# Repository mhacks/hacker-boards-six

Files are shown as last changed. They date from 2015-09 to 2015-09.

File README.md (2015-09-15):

MHacks Six Hacker Boards
============
This repository contains the support files for the MHacks 6 Hacker Boards, presented at the Intro to Hardware Workshop ([presentation can be found here](https://docs.google.com/presentation/d/15O3TXqOf3Xi9S6ba83HRF5j0ccdkGcIPRQTYAptkbrs/edit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)). In the hardware folder is copies of the Eagle schematic and board layout for the board given to participants, and in the firmware folder is the library to simplify working with the board's LEDs, button, and potentiometer/knob - also called "peripherals".

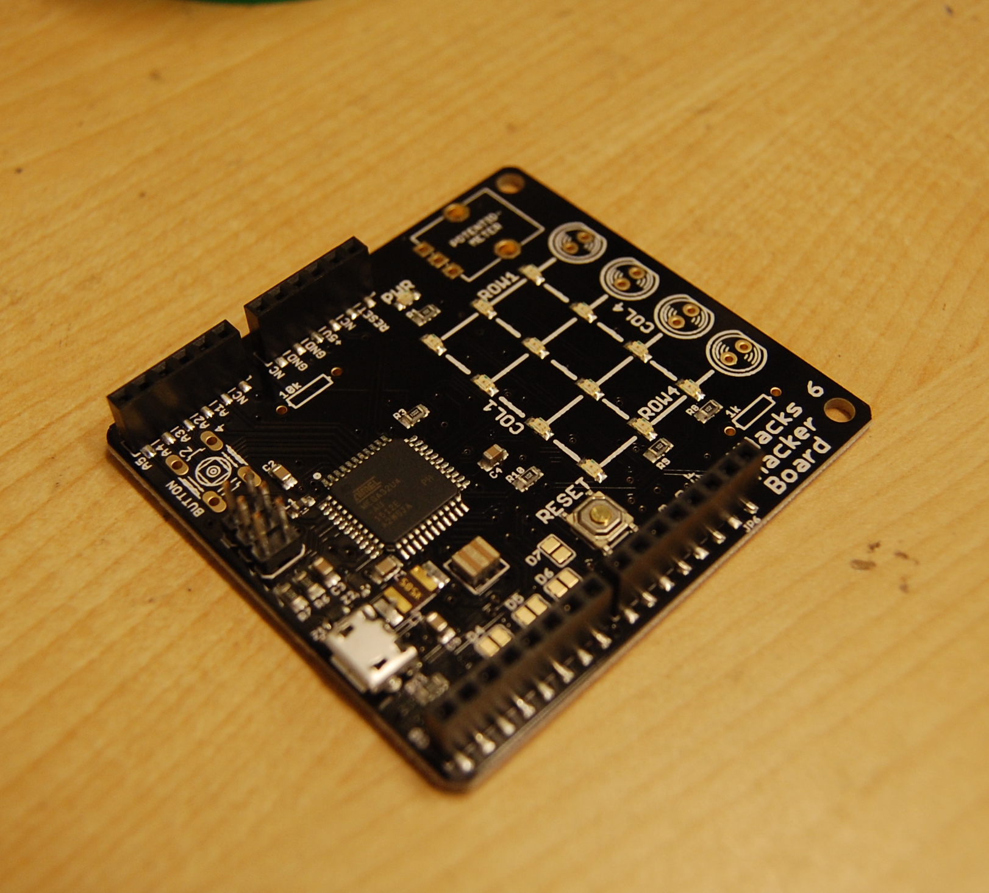
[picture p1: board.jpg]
A pretty Arduino LED shield

The MHacks Six Hacker Board. You like it? You should have come to the MHacks Six Intro to Hardware Workshop!

###How to Install the Library
* Inside of the Arduino IDE, go to Sketch->Import Library->Add Library.
* Choose the *HackerBoard* folder inside of the firmware folder.
* The Arduino IDE handles the rest!
* Be sure to check out the example animation (File->Examples->HackerBoard) if you're unsure how to work with the library, or what to do!

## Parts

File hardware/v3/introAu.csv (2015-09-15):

Part | Value | Device | Package | Description | Quantity |  | Digikey Part #
C1, C2 | 100nF | C-EUC0805 | C0805 | CAPACITOR, European symbol | 2 | 8 | 1276-1007-1-ND
JP1, JP2 |  | M06SMD-STRAIGHT-COMBO | 1X06_SMD_STRAIGHT_COMBO | Header 6 | 2 | 8 | S5598-ND
JP3, JP4 |  | M08SMD-COMBO | 1X08_SMD_COMBINED | Header 8 | 2 | 8 | S5600-ND
JP5 |  | M03X22X3_SILK_SM | 2X3 | 2x3 .1" header. | 1 | 4
L1 |  | WE-CBF_0805(WB/HS) | WE-CBF_0805(W=3.0) | WE-CBF SMD EMI Suppression Ferrite Bead | 1 | 4 | MH2029-300YCT-ND
LED1, LED17-28 |  | LEDCHIPLED_0805 | CHIPLED_0805 | LED | 13 | 52 | 160-1175-1-ND
LED4, LED9, LED10, LED14 |  | LED5MM | LED5MM | LEDs | 4 | 16 | 160-1952-ND
Q1 | CERAMIC_RESONATOR_SMD6M00G53Z | CERAMIC_RESONATOR_SMD6M00G53Z | CERAMIC_RESONATOR_SMD | Resonator | 1 | 4
R1, R2, R8, R9, R10 | 1k | R-US_R0805 | R0805 | RESISTOR, American symbol | 5 | 20 | RMCF0805JT1K00CT-ND
R5 | 10k | 1KOHM1/4W5%(PTH)HORIZ-KIT | AXIAL-0.3EZ | RES-08380 | 1 | 4 | CF14JT1K00CT-ND
R6, R7 | 22 | R-US_R0805 | R0805 | RESISTOR, American symbol | 2 | 8 | RMCF0805JT22R0CT-ND
S1 |  | TACT_BUTTON | B3F-10XX | OMRON SWITCH | 1 | 4 | SW400-ND
U$2 | ATMEGA32U4TQFP | ATMEGA32U4TQFP | SPARKFUN-DIGITALIC_TQFP44 |  | 1 | 4 | ATMEGA32U4-AU-ND
U$3 | USB_MICROB_0001LF | USB_MICROB_0001LF | USB_MICROB_CHEAPER |  | 1 | 4 | 609-4616-1-ND
U$5 |  | POT | ALPS_POT |  | 1 | 4 | P3C3103-ND
Z1, Z2 | zenor 3.6w | R-EU_R0603 | R0603 | RESISTOR, European symbol | 2 | 8 | MM3Z3V6T1GOSTR-ND | Change package to SOD-323

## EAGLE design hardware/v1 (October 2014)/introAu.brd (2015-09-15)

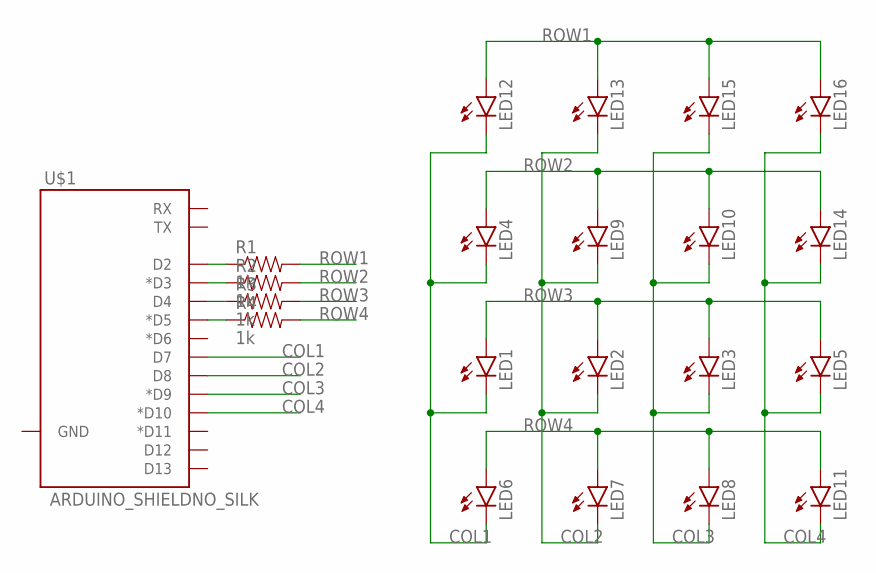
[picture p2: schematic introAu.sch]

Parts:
LED1, LED2, LED3, LED4, LED5, LED6, LED7, LED8, LED9, LED10, LED11, LED12, LED13, LED14, LED15, LED16: LED5MM
R1, R2, R3, R4: 1k; AXIAL-0.3EZ
U$1: ARDUINO_SHIELDNO_SILK; DUEMILANOVE_VIAS

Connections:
COL1: LED1.K (C), LED4.K (C), LED6.K (C), LED12.K (C), U$1.D7
COL2: LED2.K (C), LED7.K (C), LED9.K (C), LED13.K (C), U$1.D8
COL3: LED3.K (C), LED8.K (C), LED10.K (C), LED15.K (C), U$1.D9 (*D9)
COL4: LED5.K (C), LED11.K (C), LED14.K (C), LED16.K (C), U$1.D10 (*D10)
unnamed: R1.P$1 (1), U$1.D2
unnamed: R2.P$1 (1), U$1.D3 (*D3)
unnamed: R3.P$1 (1), U$1.D4
unnamed: R4.P$1 (1), U$1.D5 (*D5)
ROW1: LED12.A, LED13.A, LED15.A, LED16.A, R1.P$2 (2)
ROW2: LED4.A, LED9.A, LED10.A, LED14.A, R2.P$2 (2)
ROW3: LED1.A, LED2.A, LED3.A, LED5.A, R3.P$2 (2)
ROW4: LED6.A, LED7.A, LED8.A, LED11.A, R4.P$2 (2)

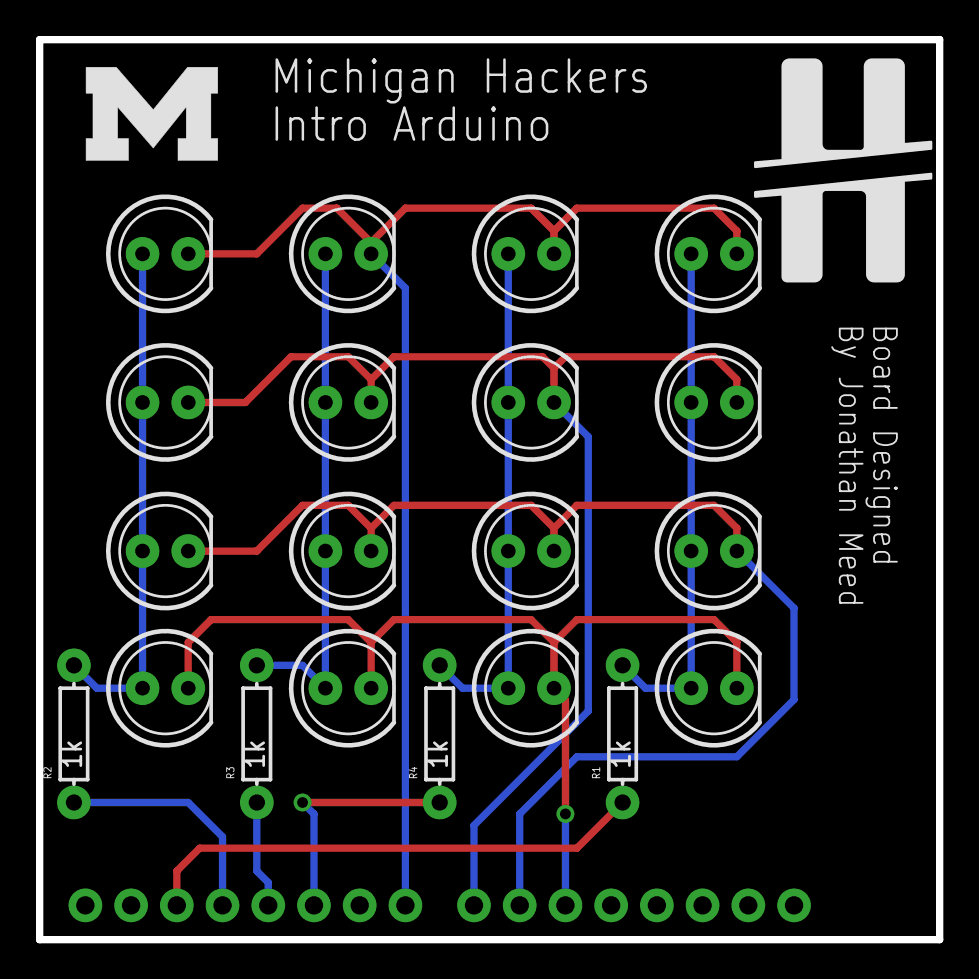
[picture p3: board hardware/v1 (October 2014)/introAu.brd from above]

Board: 2 copper layers, 50.0 x 50.0 mm, 23 parts (0 on the bottom side), 12 nets.

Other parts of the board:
U$2: SMALL-M
U$3: SMALL-MH

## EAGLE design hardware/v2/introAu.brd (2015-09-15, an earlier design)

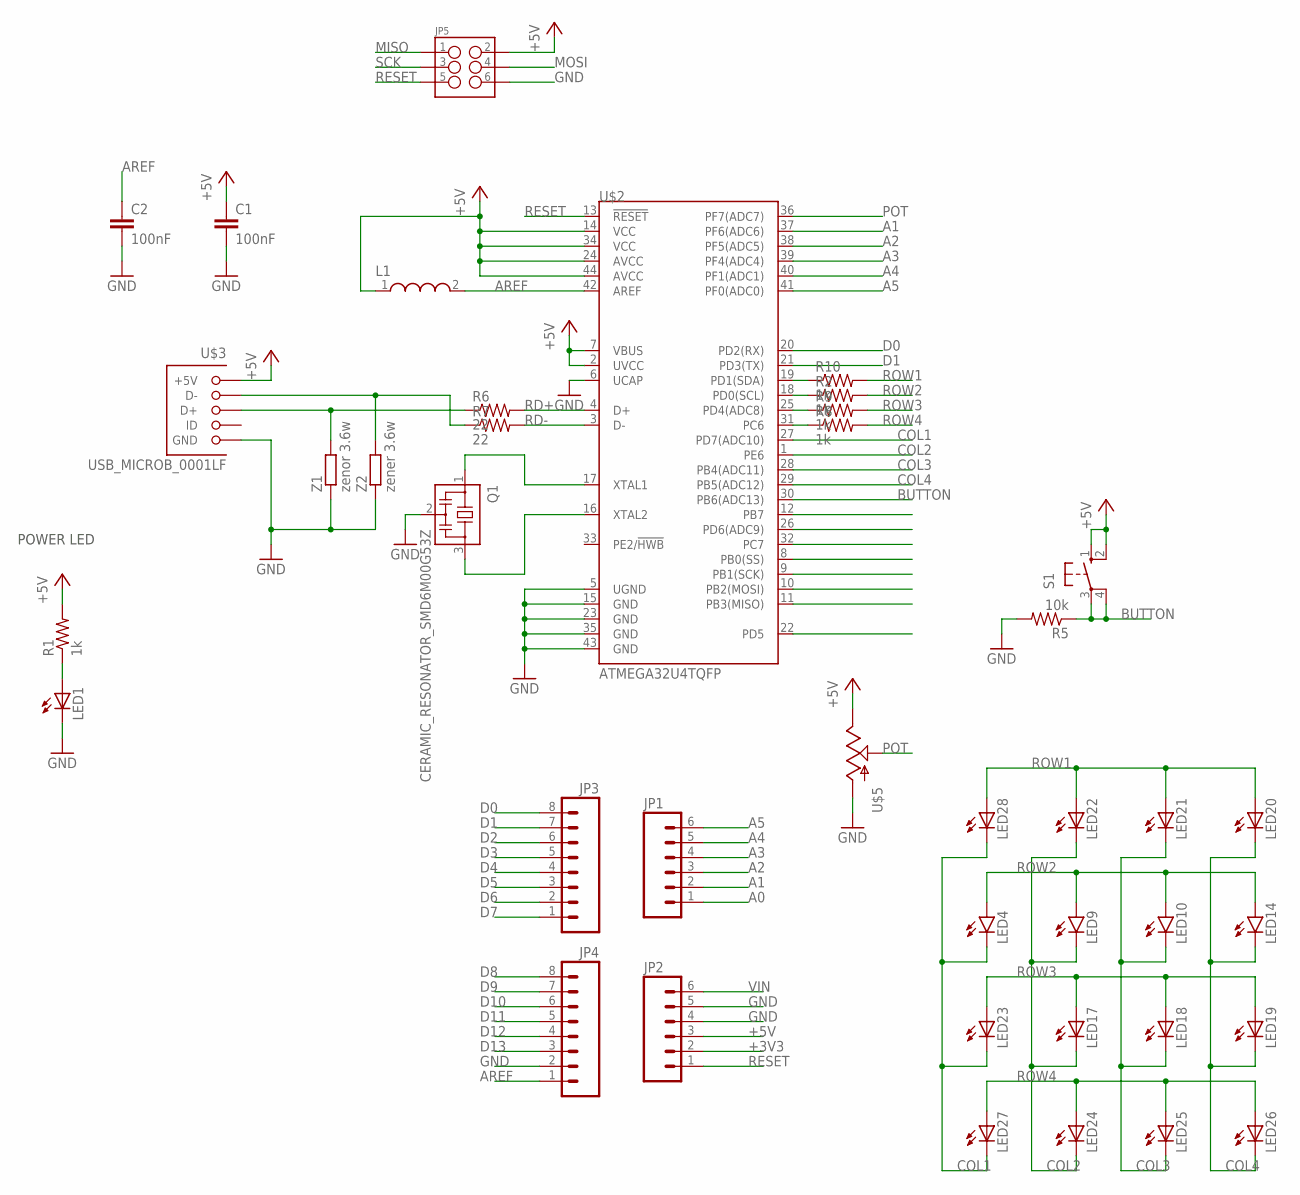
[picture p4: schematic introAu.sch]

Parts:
C1, C2: 100nF; C0805
JP1, JP2: M06SMD-STRAIGHT-COMBO; 1X06_SMD_STRAIGHT_COMBO
JP3, JP4: M08SMD-COMBO; 1X08_SMD_COMBINED
JP5: M03X22X3_SILK_SM; 2X3
L1: WE-CBF_0805(WB/HS); WE-CBF_0805(W=3.0)
LED1, LED17, LED18, LED19, LED20, LED21, LED22, LED23, LED24, LED25, LED26, LED27, LED28: LEDCHIPLED_0805; CHIPLED_0805
LED4, LED9, LED10, LED14: LED5MM
Q1: CERAMIC_RESONATOR_SMD6M00G53Z; CERAMIC_RESONATOR_SMD
R1, R8, R9, R10: 1k; R0805
R2: 1k; AXIAL-0.3EZ
R5: 10k; AXIAL-0.3EZ
R6, R7: 22; R0805
S1: TACT_BUTTON; B3F-10XX
U$2: ATMEGA32U4TQFP; SPARKFUN-DIGITALIC_TQFP44
U$3: USB_MICROB_0001LF; USB_MICROB_CHEAPER
U$5: POT; ALPS_POT
Z1: zenor 3.6w; R0603
Z2: zener 3.6w; R0603

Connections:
+3V3: JP2.2
+5V: C1.1, JP2.3, JP5.2, L1.1, R1.2, S1.1 (S), S1.2 (S1), U$2.2 (UVCC), U$2.7 (VBUS), U$2.14 (VCC), U$2.24 (AVCC), U$2.34 (VCC), U$2.44 (AVCC), U$3.P$1 (+5V), U$5.P$1 (E)
A0: JP1.1
A1: JP1.2, U$2.37 (PF6(ADC6))
A2: JP1.3, U$2.38 (PF5(ADC5))
A3: JP1.4, U$2.39 (PF4(ADC4))
A4: JP1.5, U$2.40 (PF1(ADC1))
A5: JP1.6, U$2.41 (PF0(ADC0))
AREF: C2.1, JP4.1, L1.2, U$2.42 (AREF)
BUTTON: R5.P$1 (1), S1.3, S1.4 (P1), U$2.30 (PB6(ADC13))
COL1: LED4.K (C), LED23.C, LED27.C, LED28.C, U$2.27 (PD7(ADC10))
COL2: LED9.K (C), LED17.C, LED22.C, LED24.C, U$2.1 (PE6)
COL3: LED10.K (C), LED18.C, LED21.C, LED25.C, U$2.28 (PB4(ADC11))
COL4: LED14.K (C), LED19.C, LED20.C, LED26.C, U$2.29 (PB5(ADC12))
D0: JP3.8, U$2.20 (PD2(RX))
D1: JP3.7, U$2.21 (PD3(TX))
D2: JP3.6
D3: JP3.5
D4: JP3.4
D5: JP3.3
D6: JP3.2
D7: JP3.1
D8: JP4.8
D9: JP4.7
D10: JP4.6
D11: JP4.5, U$2.12 (PB7)
D12: JP4.4, U$2.26 (PD6(ADC9))
D13: JP4.3, U$2.32 (PC7)
D14: U$2.11 (PB3(MISO))
D15: U$2.9 (PB1(SCK))
D16: U$2.10 (PB2(MOSI))
D17: U$2.8 (PB0(SS))
GND: C1.2, C2.2, JP2.4, JP2.5, JP4.2, JP5.6, LED1.C, Q1.2, R5.P$2 (2), U$2.5 (UGND), U$2.6 (UCAP), U$2.15 (GND), U$2.23 (GND), U$2.35 (GND), U$2.43 (GND), U$3.P$4 (GND), U$5.P$3 (A), Z1.1, Z2.1
MISO: JP5.1
MOSI: JP5.4
unnamed: R10.1, U$2.19 (PD1(SDA))
unnamed: R2.P$1 (1), U$2.18 (PD0(SCL))
unnamed: R9.1, U$2.25 (PD4(ADC8))
unnamed: R8.1, U$2.31 (PC6)
unnamed: Q1.3, U$2.16 (XTAL2)
unnamed: Q1.1, U$2.17 (XTAL1)
unnamed: R7.1, U$3.P$2 (D-), Z2.2
unnamed: R6.1, U$3.P$3 (D+), Z1.2
unnamed: LED1.A, R1.1
POT: U$2.36 (PF7(ADC7)), U$5.P$2 (S)
RD+: R6.2, U$2.4 (D+)
RD-: R7.2, U$2.3 (D-)
RESET: JP2.1, JP5.5, U$2.13 (!RESET)
ROW1: LED20.A, LED21.A, LED22.A, LED28.A, R10.2
ROW2: LED4.A, LED9.A, LED10.A, LED14.A, R2.P$2 (2)
ROW3: LED17.A, LED18.A, LED19.A, LED23.A, R9.2
ROW4: LED24.A, LED25.A, LED26.A, LED27.A, R8.2
SCK: JP5.3
TX: U$2.22 (PD5)
VIN: JP2.6

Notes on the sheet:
POWER LED

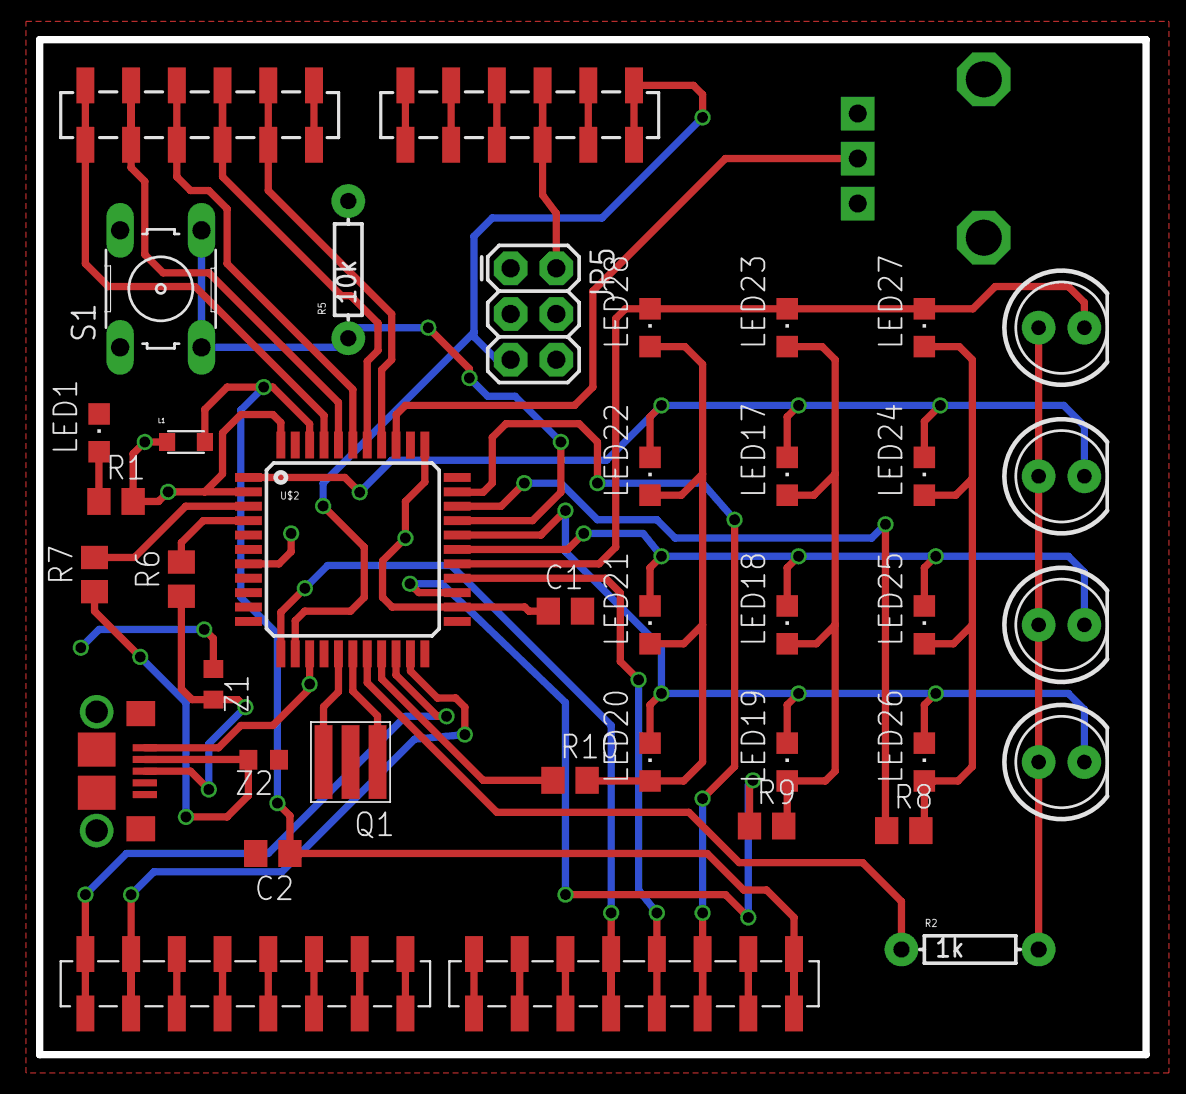
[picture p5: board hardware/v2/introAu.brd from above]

Board: 2 copper layers, 61.5 x 56.4 mm, 40 parts (0 on the bottom side), 35 nets.

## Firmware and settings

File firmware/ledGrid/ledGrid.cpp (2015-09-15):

#include "ledGrid.h"


int colPins[rows] = {8,9,11,12};
int rowPins[cols] = {4,5,6,7};
//int rowPins[rows]={3,4,5,2};
//int colPins[cols]={7,8,9,10};
int pinmode[15];
void setmode(){
  for (int i = 0; i < rows; i++){
    pinMode(rowPins[i], pinmode[rowPins[i]]);
  }  
  for (int i = 0; i < cols; i++){
   pinMode(colPins[i], pinmode[colPins[i]]);
  }
  
    
}
void reset(){
  for (int i = 0; i < rows; i++){
    digitalWrite(rowPins[i], LOW);
    pinmode[rowPins[i]] = INPUT;
  }  
  for (int i = 0; i < cols; i++){
    digitalWrite(colPins[i], LOW);
    pinmode[colPins[i]] = INPUT;
  }
    setmode();
}



void on(int r, int c){
  reset();
  pinmode[rowPins[r]] = OUTPUT;
  pinmode[colPins[c]] = OUTPUT;
  setmode();
  digitalWrite(rowPins[r], HIGH);
  digitalWrite(colPins[c], LOW);
}


 uint16_t CountSetsBits (uint16_t  x){
      uint16_t count;
      for (count = 0; x; count++)
          x &= x - 1; 
      return count;
    }

//writes an image from a 16-bit string and display it in time in mill
void writeImage(uint16_t hexVal, int time) {
  signed int imageTime;
  imageTime = time * 10; 
  while (imageTime > 0){
    int i = 0;
     for (uint16_t mask = 00000001; mask>0; mask <<= 1) { //iterate through bit mask
       if (hexVal & mask){
         on(i/4,i%4);
         delayMicroseconds(250);
      }
      i++;
    }
    imageTime--;
  }
}

void writeAnimation(uint16_t *hexVals, int size, int time, int reverse){
  if (reverse == 0) {
    for (int i =0; i < size; i++){
      writeImage(hexVals[i], time);
    }
  } else {
     for (int i =size-1; i >= 0; i--){
      writeImage(hexVals[i], time);
     }
  }
}

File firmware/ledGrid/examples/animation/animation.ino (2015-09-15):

#include "ledGrid.h"

uint16_t animation1[8]={
  0x1000,
  0x2100,
  0x4210,
  0x8421,
  0x0842,
  0x0084,
  0x0008,
  0x0000
};

uint16_t animation2[2]={
  0xf99f,
  0x0660
};



void setup() {                
  // initialize the digital pin as an output.
  reset();

}
// the loop routine runs over and over again forever:
void loop() {
writeAnimation(animation1, 8, 5, 0);
writeAnimation(animation1, 8, 5, 1);
writeAnimation(animation1, 8, 5, 0);
writeAnimation(animation1, 8, 5, 1);
  for (int i = 0; i < 10; i++){
    writeAnimation(animation2, 2, 5, 0);
    writeAnimation(animation2, 2, 5, 1);
  }
}

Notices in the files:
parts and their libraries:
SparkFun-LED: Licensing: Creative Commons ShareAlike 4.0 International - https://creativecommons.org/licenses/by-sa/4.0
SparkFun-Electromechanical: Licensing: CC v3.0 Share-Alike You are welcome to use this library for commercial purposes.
